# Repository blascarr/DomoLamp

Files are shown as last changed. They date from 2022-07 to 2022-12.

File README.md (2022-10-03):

# DomoLamp
**DomoLamp** is an open source **IOT lamp** controlled with a **MQTT server** which could be connected with any other API platform, such as Twitter, Instagram, Facebook or any other API on your own.
Also can be connected with **Node-Red** Server in order to define some other complex logic behavior.

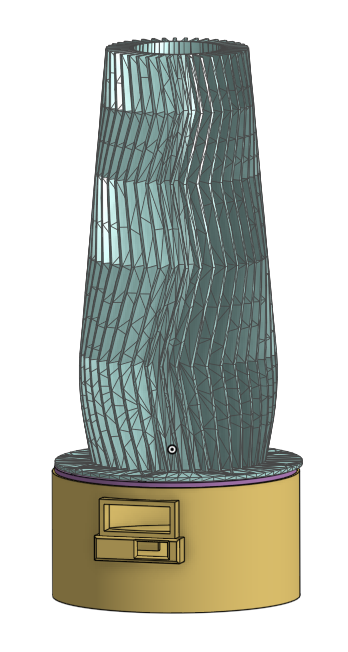
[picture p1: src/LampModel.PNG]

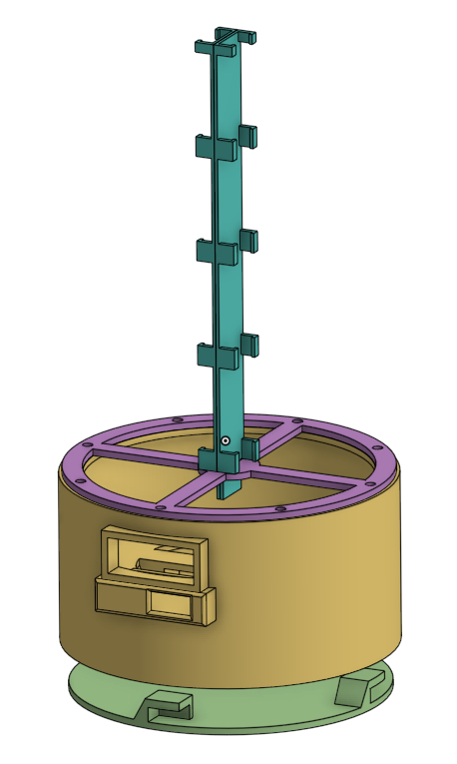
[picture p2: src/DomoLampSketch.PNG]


## Purpose Idea

The original idea is used to **express emotions** with different colours and effects for eduational purposes with kids. Also used if adults and kids lives far away from each other.

At first, the lamp represents the emotion of an adult ( controlled through a webpage ) in order to express adults feelings for kids to learn that big people can feel the same.

- **GREEN** → **Relaxed**
- **BLUE** → **Sadness**
- **RED** → **Angry**
- **YELLOW** → **Happiness**
- **PINK**→ **In Love**
- **PURPLE** → **Fear**
- **ORANGE** → **Excitement**
- **SEA** → **Creative**
- **WHITE** → *Used for Configuration*

## BOM ( Bill of Materials)

- ESP module ( Wemos )
- [Neopixel Leds](https://www.aliexpress.com/item/4000113154702.html) ( 5V, IP65, Indexed 2812 )
- [LiPo Battery 3.7V](https://es.aliexpress.com/item/1005002919536938.html) **2000mAh**
- Battery Charger
    - [Model DC Step-Up 18650](https://www.aliexpress.com/item/32986165837.html) ( Vout regulator )
    - [Model **18650 TP4056](https://www.aliexpress.com/item/32930640893.html) (** Vout 5V )
- [Rocker Switch](https://www.aliexpress.com/item/32979907338.html)
- [JST Connector](https://www.aliexpress.com/item/32954379535.html)
- PLA 3D Print plastic
    - Transparent PLA for **DomoLamp** piece
    - Any other colour for the rest.

## Print Recommendations

Use **Spiralize Outer Contour** in **Ultimaker Cura** Software to print the lamp with transparent colour with a thin layer in order to print it reflective for LED lights.  

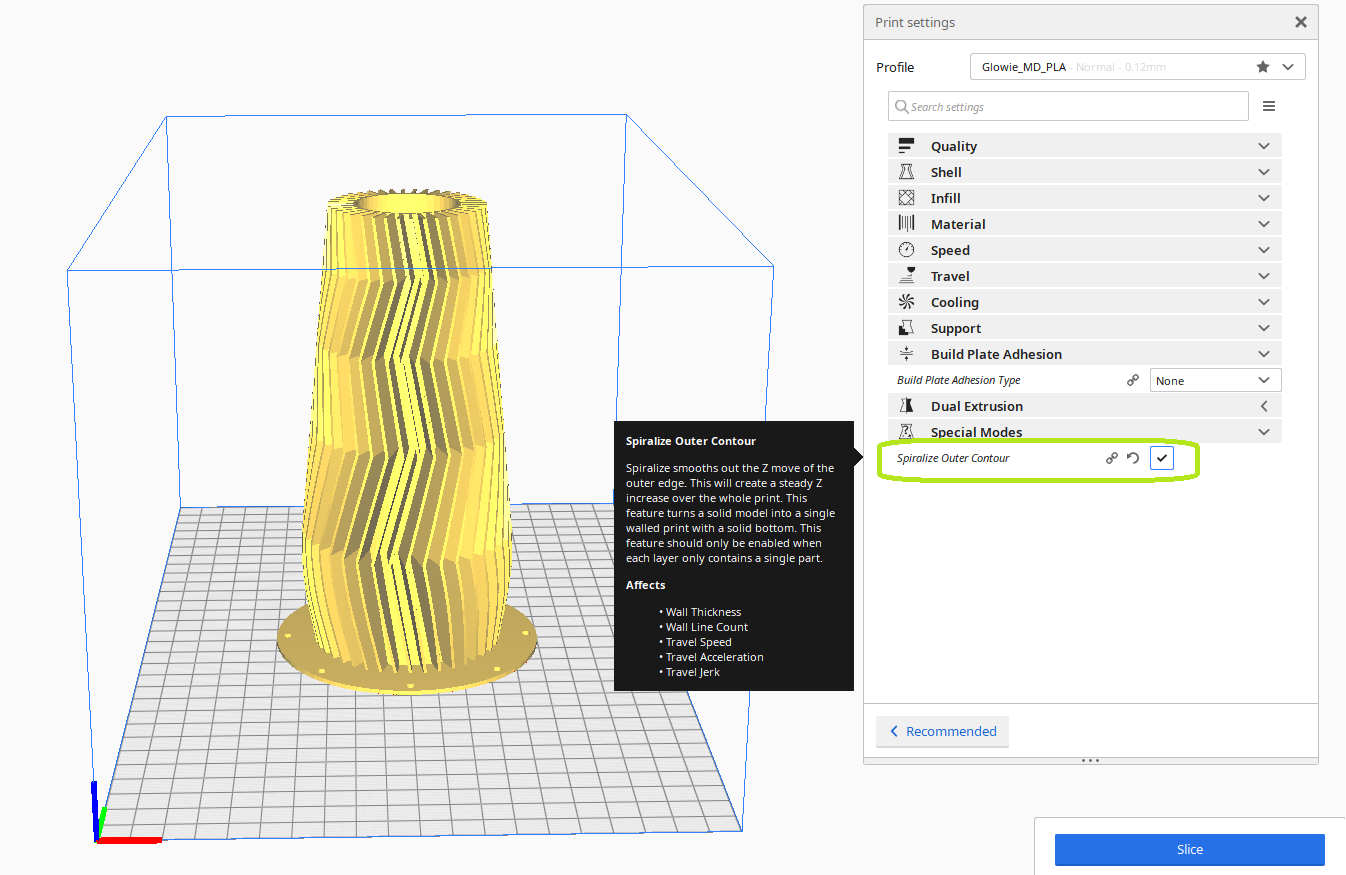
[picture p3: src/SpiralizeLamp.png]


## Libraries Required

- [ESP Async WifiManager](https://github.com/khoih-prog/ESPAsync_WiFiManager)
- [ArduinoJSON](https://arduinojson.org/)
- [Adafruit_NeoPixel](https://github.com/adafruit/Adafruit_NeoPixel)
- [AsyncMqttClient](https://github.com/marvinroger/async-mqtt-client)
- [Ticker](https://github.com/sstaub/Ticker)
- [ArduinoOTA](https://github.com/jandrassy/ArduinoOTA)
- [ESPAsyncWebServer](https://github.com/me-no-dev/ESPAsyncWebServer)
- ESP8266
    - ESP8266WiFi
- ESP32

## Electronic Wiring with battery charger

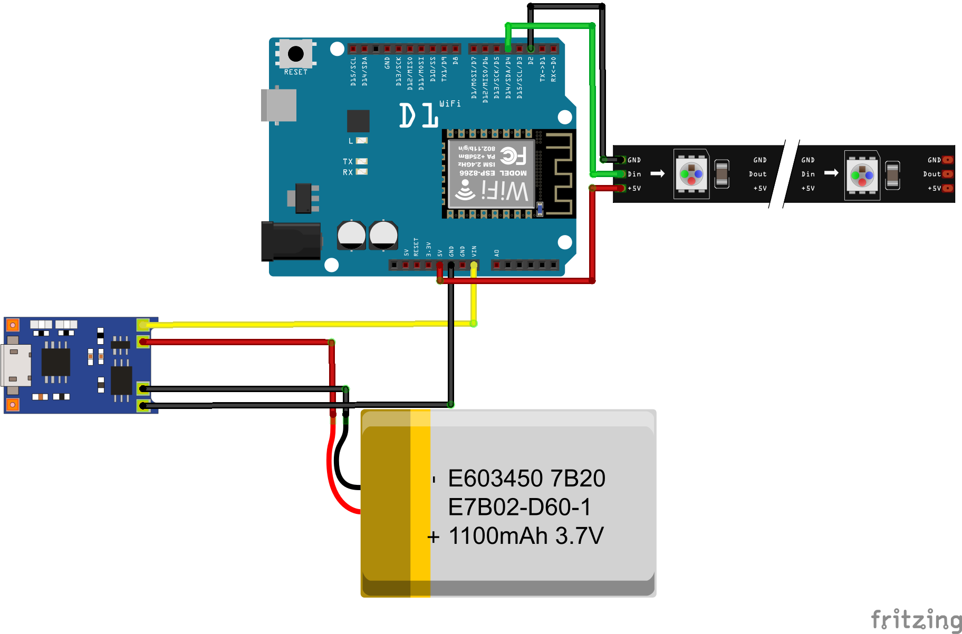
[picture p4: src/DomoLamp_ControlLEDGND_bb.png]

* LED Control Pin to GND LEds for current protection for WiFi and LED current consumption.
## Data JSON Structure sent through Node-Red

### Simple Node-Red configuration used with MQTT Server

**Topic** configured in Node Red should be the same as in **config.h** sketch file. 

**IMPORTANT:** **retain** set to **true** for retaining last message while Lamp is disconnected. 

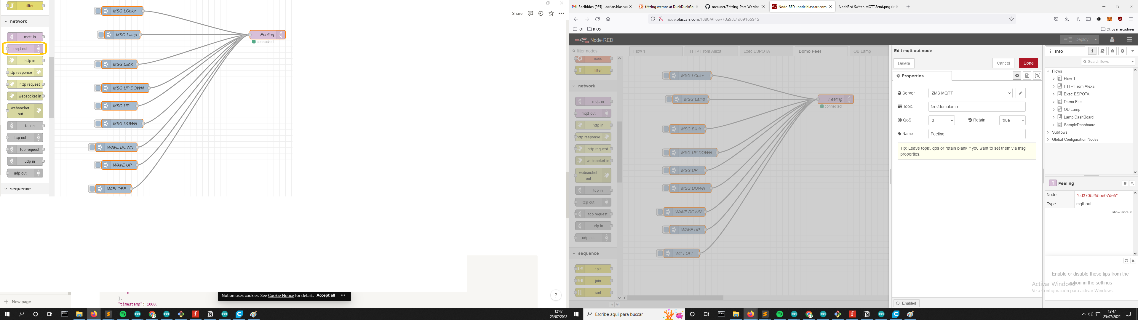
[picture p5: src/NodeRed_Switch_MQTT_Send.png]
NodeRed Switch MQTT Send.png


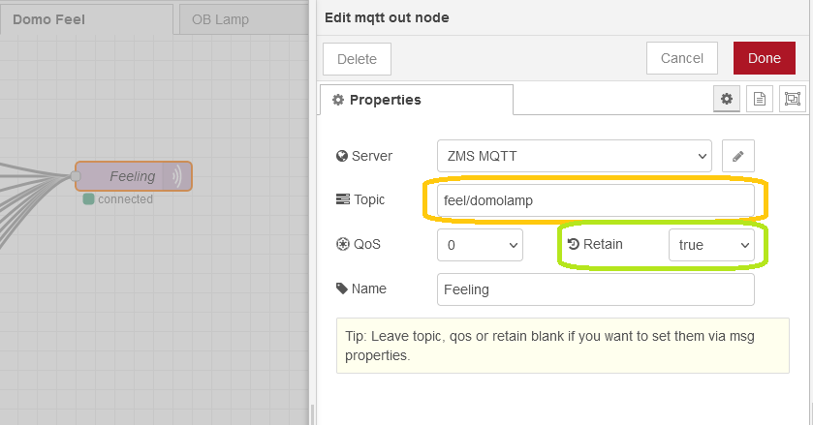
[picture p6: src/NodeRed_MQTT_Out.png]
NodeRed MQTT Out.png


### JSON Structure

```jsx
{
    "RGBColor": [
        0,
        255,
        0
    ],
    "timestamp": 1000,
    "timestop": 5000,
    "speed": 100,
    "latency": 2000,
    "effect": "COLOR"
}
```

### Node Red UI Dashboard

Dashboard configuration to create a user interface controlled webpage Domolamp with MQTT server defined in Node-Red and access to your **Node-Red** host **http:localhost:1880/ui**

[**Demo Node Red**](http://node.blascarr.com:1880/ui/) in production with **feel/domolamp** topic.

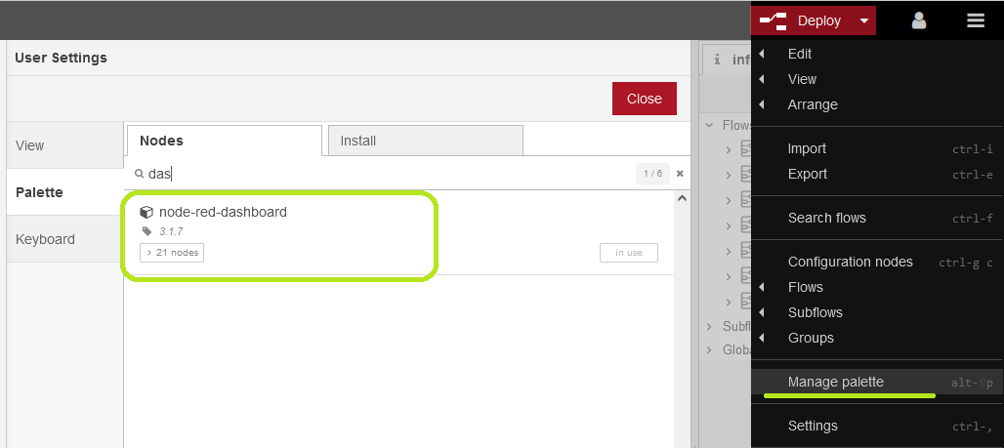
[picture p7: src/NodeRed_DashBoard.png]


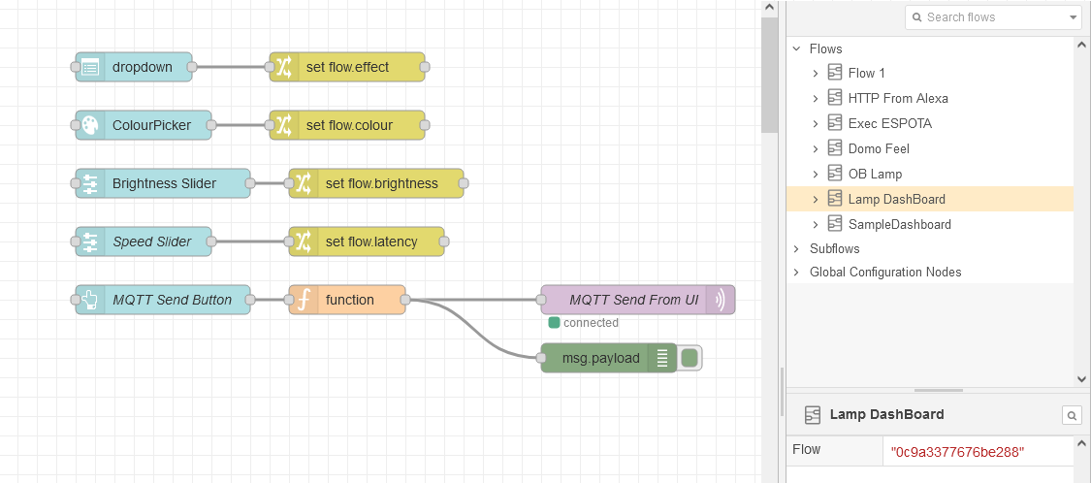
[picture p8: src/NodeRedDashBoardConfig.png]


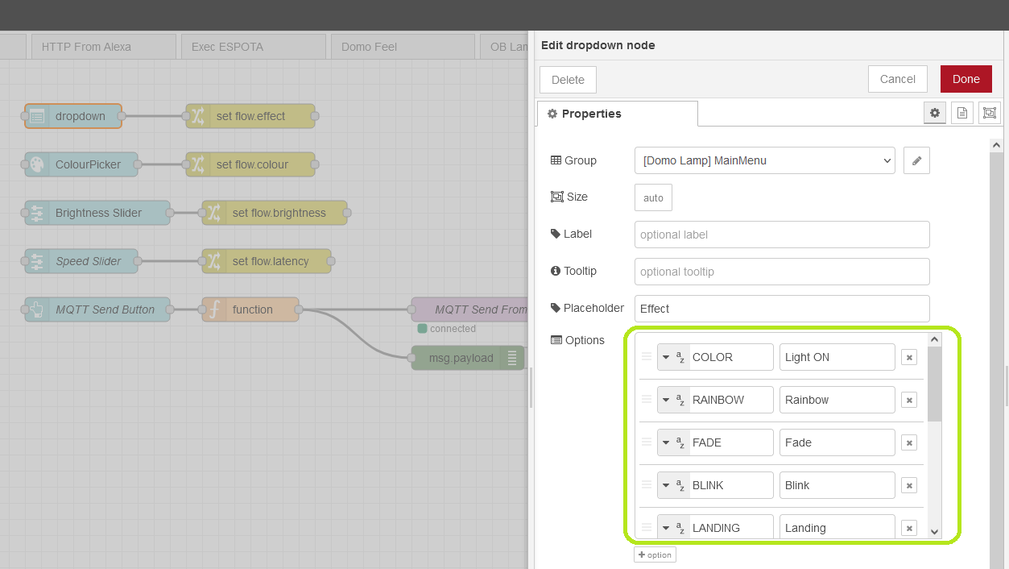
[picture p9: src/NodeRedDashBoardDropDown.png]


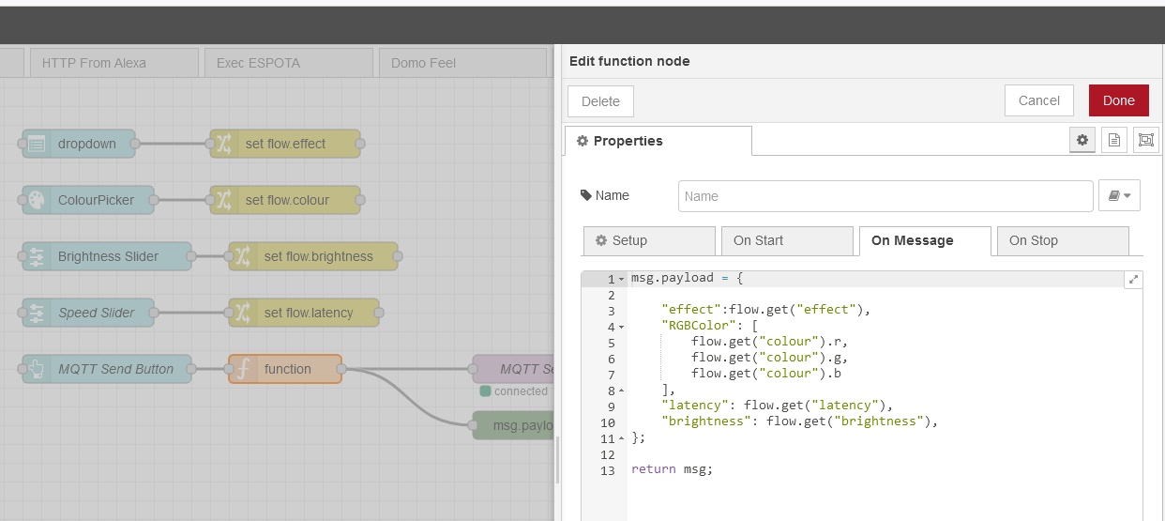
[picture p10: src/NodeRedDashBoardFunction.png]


### Effects included

- COLOR
- BLINK
- RAINBOW
- FADE
- UPDOWN
- LANDING
    - UPLANDING
    - DOWNLANDING
- WAVE
    - UPWAVE
    - DOWNWAVE
- WIFIOFF
- OFF

## Configuration File

In **Config.h** , DomoLamp can be defined with parameters. 

DomoLamp use **WifiManager** to connect it to the local network. Configuration webpage through **192.168.4.1** IP address when a device is connected to **DOMO LAMP** network.

Just only credentials are required for **MQTT Server** and other configurations are used to select topic used in controlled with the structured explained before.

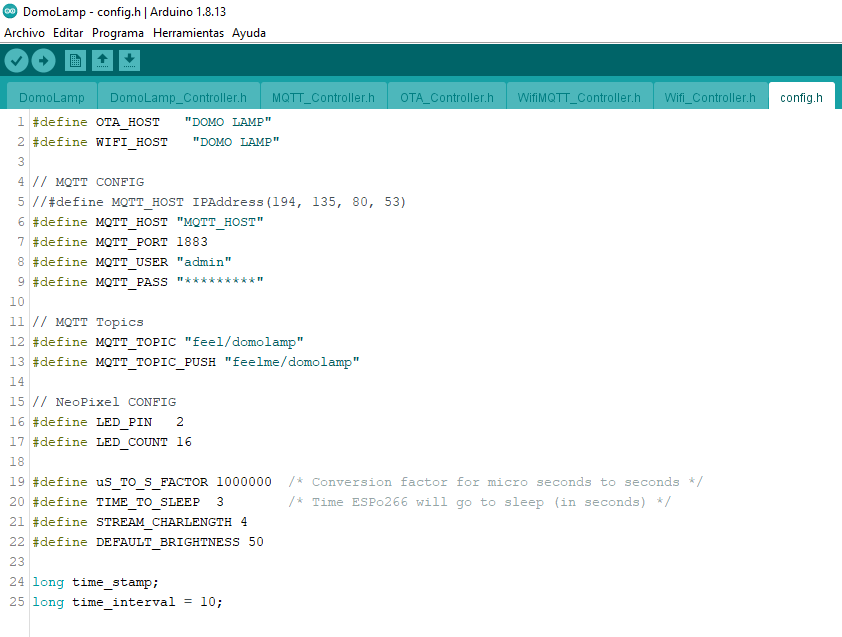
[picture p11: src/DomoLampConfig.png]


## FAQ

### What can i do if Lamp doesn’t connect to my WiFi network?

If some problems with local network connection occured, you can create a previous network credentials with your phone from **adjustments** → **wireless connection** → **personal access point**.

If lamp can’t connect from other place, you can reset settings, sending **WIFIOFF** effect **through your MQTT Server**.

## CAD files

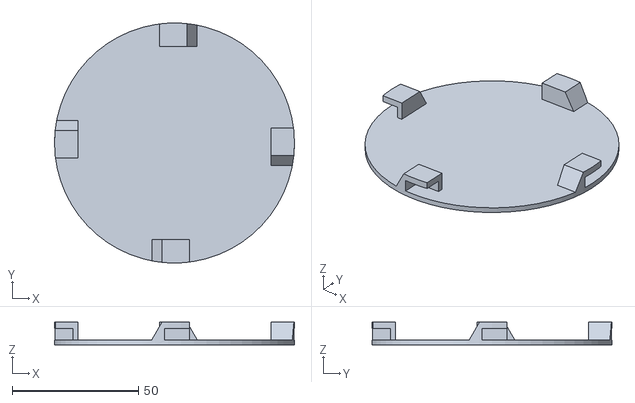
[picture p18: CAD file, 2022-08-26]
stl/TapBottom.stl
95.0 x 94.9 x 9.00

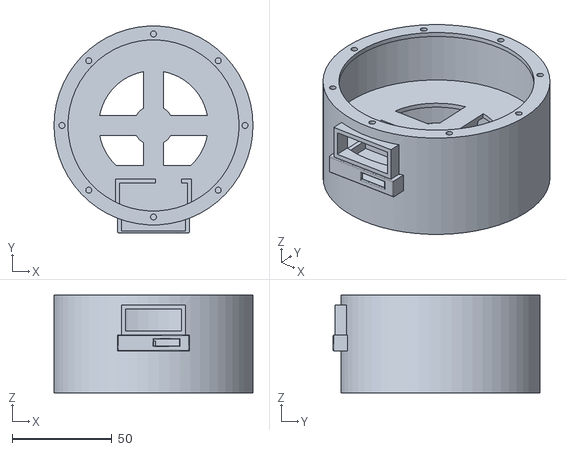
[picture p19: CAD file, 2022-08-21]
stl/BaseBattery1700ChargerRegulator.stl
100.0 x 103.9 x 49.0

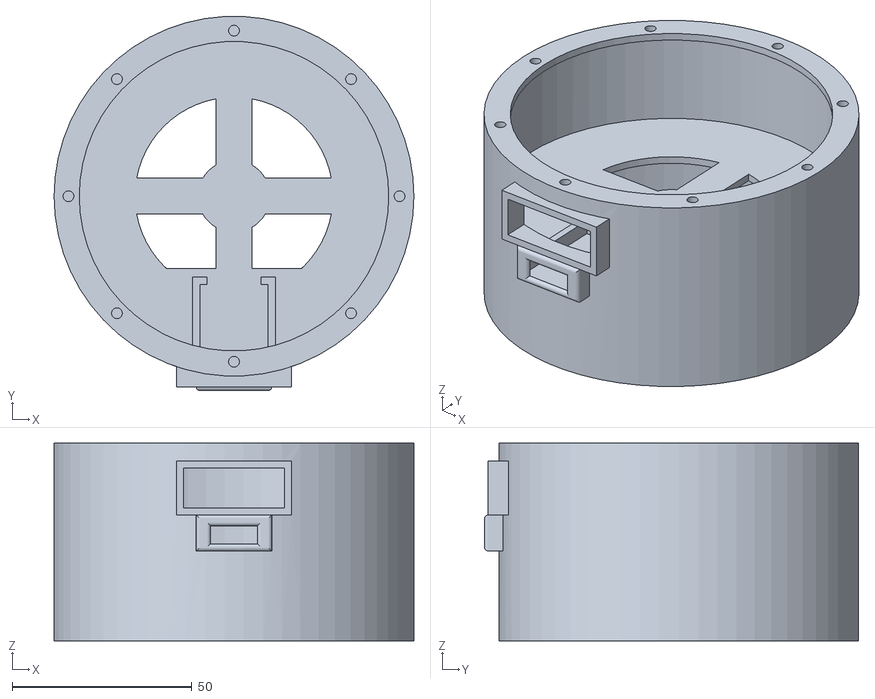
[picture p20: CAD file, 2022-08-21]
stl/BaseBattery2000MiniCharger.stl
100.0 x 103.9 x 55.0

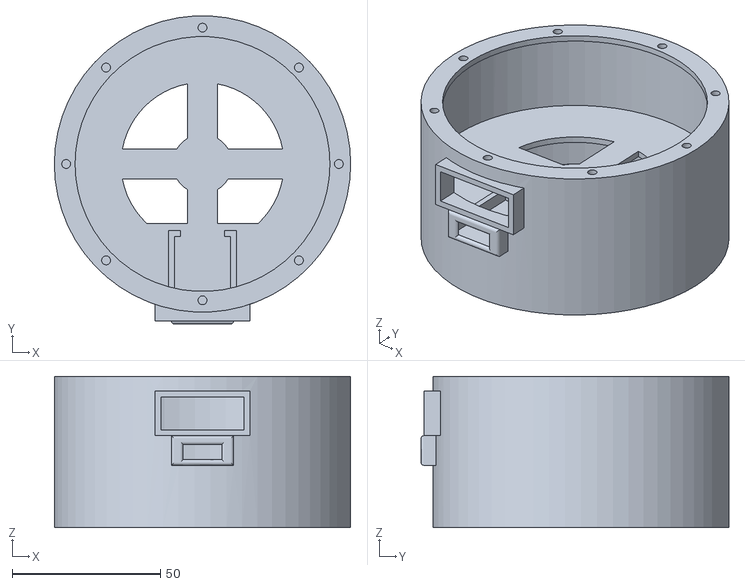
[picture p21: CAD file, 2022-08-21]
stl/BaseBattery1700MiniCharger.stl
100.0 x 103.9 x 51.0

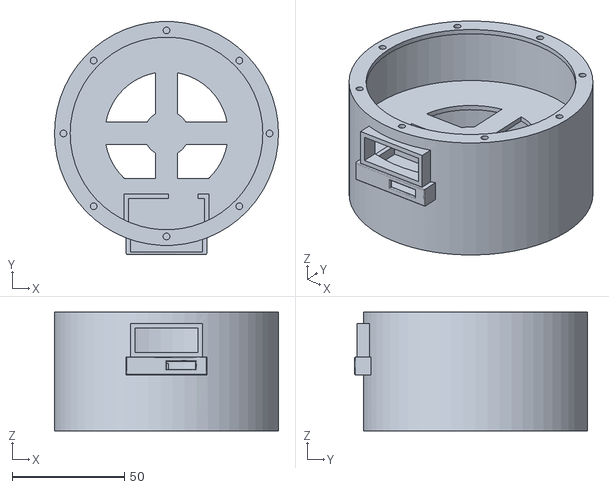
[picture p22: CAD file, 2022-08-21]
stl/BaseBattery2000ChargerRegulator.stl
100.0 x 103.9 x 53.0

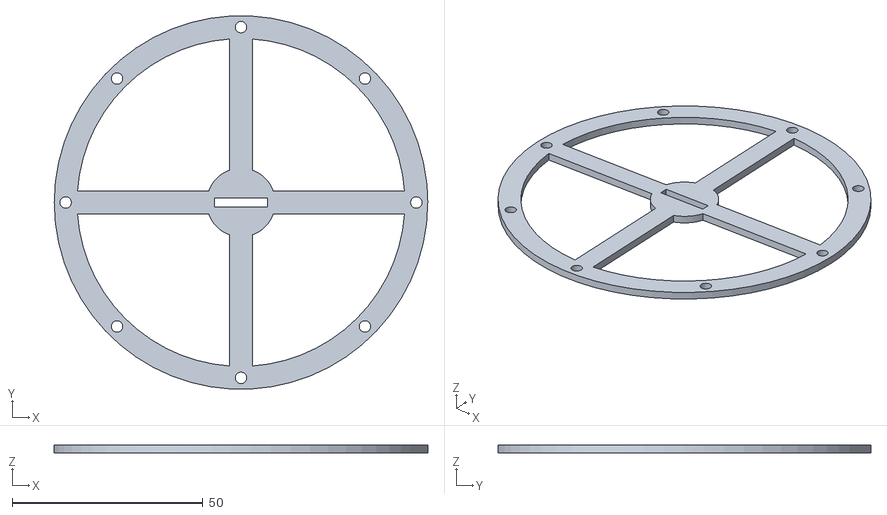
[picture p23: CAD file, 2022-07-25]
stl/Support.stl
98.0 x 97.9 x 2.00

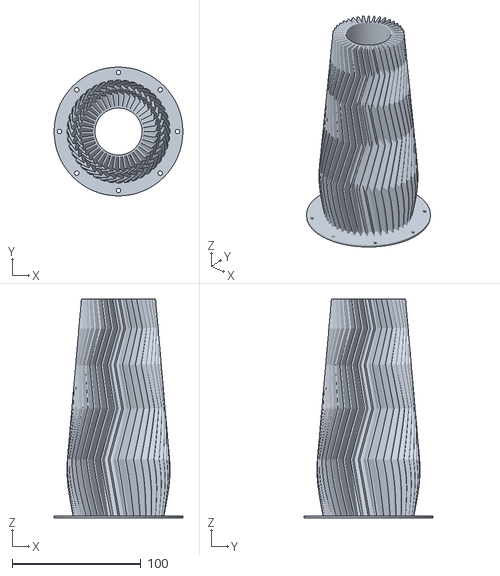
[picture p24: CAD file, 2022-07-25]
stl/DomoLamp.stl
100.0 x 100.0 x 170.0

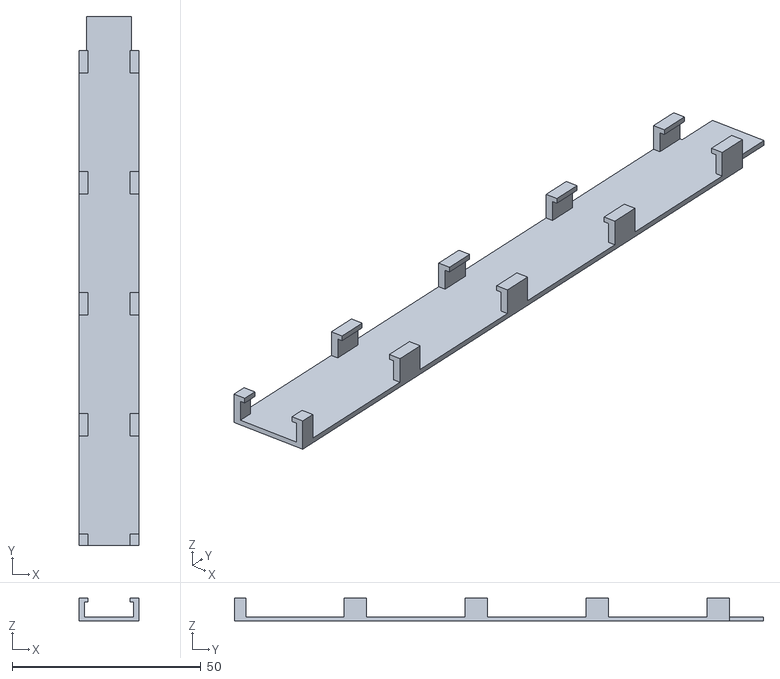
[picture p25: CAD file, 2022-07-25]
stl/LedStrip.stl
16.0 x 140.0 x 6.00

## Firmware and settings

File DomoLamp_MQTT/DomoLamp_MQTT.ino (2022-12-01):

#include "config.h"
#include "Debug_Controller.h"

#include <Ticker.h>
#include <Arduino_JSON.h>

#include "DomoLamp_Controller.h"
DomoLamp strip(LED_COUNT, LED_PIN, NEO_GRB + NEO_KHZ800);

#include "Server_Controller.h"
#include "WifiManager_Controller.h"
#include "Lamp_Controller.h" 

#include "OTA_Controller.h"
#include "Wifi_Controller.h" 
#include "MQTT_Controller.h"

#include "WifiEvents_Controller.h" 

void setup() {
  Serial.begin(115200);   
  DUMPPRINTLN();
  
  pinMode( LED_PIN, OUTPUT);
  pinMode( POWERCONTROL_PIN, OUTPUT);
  strip.reset();  //SET GND to HIGH in order to avoid current overflow

  onWifiEvents();
  #if OTA
    OTA_init();
  #endif
  strip.init();
  MQTT_init();
  
  bool isConnected = connectToWifi();
  if( isConnected ){
    DUMPSLN("IS WIFI CONNECTED");
    initWebServer();
    connectToMqtt();

    if(!domolampTicker.active() ){
      DUMPSLN("Ticker Domolamp Init ");
      #if NOTIFY
          strip.clean();
          strip.fill( NOTIF_GREEN, NOTIFY_LEDS, NOTIFY_LEDS );
          strip.show(); 
      #endif
      domolampTicker.attach_ms( time_interval, striploop );
    }
  }
  
}

void loop() {
  #if OTA
    ArduinoOTA.handle();
  #endif
}

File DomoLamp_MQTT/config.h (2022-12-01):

// ---------------------------------------------------//
// ------------------ WiFi and MQTT ------------------//
// ---------------------------------------------------//
/* --- Set Up Wifi Parameters and MQTT Credentials ---*/
// ------------------ WIFI CONFIG --------------------//

#define WIFIMANAGER   true
#define WIFI_SSID   "SSID"
#define WIFI_PASS   "********"
#define WIFI_HOST   "DOMO_LAMP"
#define LOCAL_IP IPAddress(192, 168, 1, 180)

// ------------------ MQTT CONFIG --------------------//
#define MQTT_HOST_LEN           64
#define MQTT_PORT_LEN           6
#define MQTT_USER_LEN           32
#define MQTT_PASS_LEN           32
#define MQTT_TOPIC_LEN          16
#define MQTT_ACKTOPIC_LEN       16
#define MQTT_QOS                1

char MQTT_HOST [MQTT_HOST_LEN]    = "broker.emqx.io";   //  https://www.emqx.com/en/blog/popular-online-public-mqtt-brokers
char MQTT_PORT   [MQTT_PORT_LEN]  = "1883";
char MQTT_TOPIC   [MQTT_TOPIC_LEN]   = "domo/";
char MQTT_ACKTOPIC   [MQTT_ACKTOPIC_LEN]   = "ack/";
#define MQTT_TOPIC_ID_LEN         16
char DOMOLAMP_ID  [MQTT_TOPIC_ID_LEN]   = "lamp/1";

#define MQTT_CREDENTIALS false
char MQTT_USER  [MQTT_USER_LEN]   = "admin";
char MQTT_PASS  [MQTT_PASS_LEN]   = "*******";

// ---------- NeoPixel CONFIG ---------- //
#define LED_PIN   2
#define LED_COUNT 16
#define POWERCONTROL_PIN   4

// ------------ WIFI CONFIG ------------ //
#define GATEWAY IPAddress(192, 168, 1, 1)
#define SUBNET IPAddress(255, 255, 0, 0)
#define PRIMARYDNS IPAddress(9, 9, 9, 9)
#define SECONDARYDNS IPAddress(208, 67, 222, 222)
#define WIFI_RECONNECT_TIMER_S   20

// ------------ MQTT CONFIG ------------ //
#define MQTT_RESET_MAXTRIES  50
int mqtt_reset_trycounter = 0;

// ----------- SERVER CONFIG ----------- //
#define SERVER_ENDPOINT "/domo"
#define SERVER_EVENTS_ENDPOINT "/domo_events"
#define DATA_REQUEST_INPUT "LampData"
#define SERVER_PORT  80

// ---------- OTA CONFIG ---------- //
#define OTA           false
#define OTA_HOST   "DOMO_LAMP"

// ---------- TEST CONFIG ---------- //
#define NOTIFY true
#define NOTIFY_LEDS 2

// ----------- SLEEP CONFIG ----------- //
#define uS_TO_S_FACTOR 1000000  /* Conversion factor for micro seconds to seconds */
#define SLEEP_TIME_LEN    10
char SLEEP_TIME  [SLEEP_TIME_LEN] = "3000";

// ---------- STREAM CONFIG ----------- //
#define STREAM_CHARLENGTH 4
#define DEFAULT_BRIGHTNESS 50

// ---------- SERIAL CONFIG ----------- //
#define SERIAL_DEBUG true
#define SERIAL_CONTROL true
long serial_latency = 200;
long serial_millis;

#if SERIAL_DEBUG
    #define SERIALDEBUG Serial
#endif

long time_stamp;
long time_interval = 10;

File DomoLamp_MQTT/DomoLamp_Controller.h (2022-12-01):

#include <Adafruit_NeoPixel.h>

enum modes { UNDEF, COLOR, BLINK, UPDOWN, RAINBOW, FADE, UPWAVE, DWAVE, LANDING, UPLANDING, DOWNLANDING, ONWIFI, NOWIFI, OFF };
enum landing_modes { UPANDDOWN, UP, DOWN };

#if NOTIFY 
  enum notif_lights : uint32_t { NOTIF_RED = 16711680, NOTIF_GREEN = 65280, NOTIF_BLUE = 255, NOTIF_WHITE = 16777215, NOTIF_BLUESEA = 65535, NOTIF_PURPLE= 10420479, NOTIF_YELLOW = 16776960 };
#endif

struct colorRGB{
  uint8_t red;
  uint8_t green;
  uint8_t blue;
};

struct statusLamp{
  uint32_t color;
  colorRGB RGBColor;
  uint16_t latency;
  uint8_t landingleds = 1;
  uint8_t bright = DEFAULT_BRIGHTNESS;
  modes effect;
  String mode;
};

class DomoLamp  : public Adafruit_NeoPixel {
    public:

      typedef void ( *_f_Strip )( );
      int brightness = DEFAULT_BRIGHTNESS;
      int fade_brightness = DEFAULT_BRIGHTNESS;
      uint8_t fade_increment = 10;
      String state;
      int pixelCycle = 0;   // Pattern Pixel Cycle in Rainbow Mode
      uint32_t color;
      long blink_millis;
      long rainbow_millis;
      statusLamp currentStatus;
      bool even = true;
      
      //LANDING MODE
      landing_modes landingMode = UP;
      uint16_t currentPixel = 0;
      uint16_t landingleds = 2;
      
      void resetWifiManager();
      typedef void ( DomoLamp::*_f_lamp )();
      _f_lamp light = &DomoLamp::idle; //Loop Controller Function
      
      DomoLamp( uint16_t n, uint16_t pin , neoPixelType type=NEO_GRB+NEO_KHZ800) : Adafruit_NeoPixel( n, pin, type ){
        this->currentStatus.color = this->Color( 0, 255, 0);
        even = !n%2;
      }
      
      void init(){
        this->begin();           // INITIALIZE NeoPixel strip object (REQUIRED)
        this->reset();           //SET GND to HIGH in order to avoid current overflow          
        this->clean();            // Turn OFF all pixels ASAP
        this->setBrightness(brightness); // Set BRIGHTNESS to about 1/5 (max = 255)
        digitalWrite(POWERCONTROL_PIN, LOW);  //SET GND to LOW connecting strip voltage      

        #if NOTIFY
          this->fill( NOTIF_GREEN , 0, NOTIFY_LEDS );
          this->show(); 
        #endif
      }
      
      void reset(){
        digitalWrite(LED_PIN, LOW);
        digitalWrite(POWERCONTROL_PIN, HIGH);
      }

      void clean(){
        this->clear();
        this->show();
      }
      
      void loop(){
        (this->*light)();
      }

      uint32_t Wheel(byte WheelPos) {
        WheelPos = 255 - WheelPos;
        if(WheelPos < 85) {
          return this->Color(255 - WheelPos * 3, 0, WheelPos * 3);
        }
        if(WheelPos < 170) {
          WheelPos -= 85;
          return this->Color(0, WheelPos * 3, 255 - WheelPos * 3);
        }
        WheelPos -= 170;
        return this->Color(WheelPos * 3, 255 - WheelPos * 3, 0);
      }

      // Rainbow cycle along whole strip. Pass delay time (in ms) between frames.
      void rainbow() {
        if( millis() - rainbow_millis >= this->currentStatus.latency ){
          rainbow_millis = millis();
          for(uint16_t i=0; i < this->numPixels(); i++) {
            this->setPixelColor(i, Wheel((i + pixelCycle) & 255)); //  Update delay time  
          }
          this->show();                             //  Update strip to match
          pixelCycle++;                             //  Advance current cycle
          if(pixelCycle >= 256)
            pixelCycle = 0;                         //  Loop the cycle back to the begining
          }        
      }

      void setStatus( String payload ){
         //DUMP("Set status from JSON: ", payload );
         JSONVar domoJSON = JSON.parse(payload);
         if (JSON.typeof(domoJSON) == "undefined") {
            DUMPSLN("Parsing input failed!");
            return;
          }
         
         if (domoJSON.hasOwnProperty("effect")) {
            int len = STREAM_CHARLENGTH;
            char messageArray[len];
            memcpy ( messageArray, (const char*)domoJSON["effect"], len );
            String message(messageArray);
            this->currentStatus.mode = message;
            DUMPS("MODE: ");
            setStatusLamp( this->currentStatus.mode );
         }

         if (domoJSON.hasOwnProperty("latency")) {
            this->currentStatus.latency = (int) domoJSON["latency"];
            DUMPLN("Latency : ", this->currentStatus.latency);
         }
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

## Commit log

2022-07-25 Project definition README and WifiOff Config
    [BaseLamp_NotRegCharger.stl, BaseLamp_RegCharger.stl, DomoLamp.stl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]
2022-07-25 Support for both ESP32 and ESP8266
2022-08-19 Publish message to broker with ID for received message
    [DomoLamp.ino, config.h]
2022-08-19 ESP32 Domolamp Sketch
2022-08-21 ESP32 Local Server Controller with WifiManager
2022-08-21 OTA Controller for ESP32
2022-08-21 Updated Base Lamp with Battery 1700mAh 2000mAh and both charger ( regulator and non-regulator)
    [BaseBattery1700ChargerRegulator.stl, BaseBattery1700MiniCharger.stl, BaseBattery2000ChargerRegulator.stl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]
2022-08-26 Tapbottom STL
    [TapBottom.stl]
2022-10-03 Clean Code and GND Control in LED Power. Connection to LED_POWERCONTROL_PIN 4
2022-10-03 ESP32 Cleaning and GND PowerControl Pin
2022-10-03 Control LED POWER Pin Schema for current consumption Protection
2022-12-01 DomoLamp Revision with no MQTT broker
    [DomoLamp.ino, DomoLamp_Controller.h]
2022-12-01 Domolamp MQTT with Free Broker
    [Async_AutoConnect.ino, Async_AutoConnectWithFSParameters.ino, Async_AutoConnectWithFSParametersAndCustomIP.ino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]
2022-12-01 DomoLamp MQTT Revision Ticker and no credentials with Free Broker
    [DomoLamp_Controller.h, config.h]
